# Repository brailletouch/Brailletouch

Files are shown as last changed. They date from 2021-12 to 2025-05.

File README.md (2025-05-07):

# BrailleTouch
Dispositivo Braille Digital Asequible y Open Source para Personas con Discapacidad Visual y Sordocieguera / Affordable and Open Source Digital Braille Device for Visually Impaired and Deafblind People

**¡Bienvenidos al repositorio del Proyecto BrailleTouch! / Welcome to the BrailleTouch Project repository!**

Este es un proyecto en **desarrollo activo**. La información, componentes y ejemplos mostrados reflejan el estado actual o intentos iniciales. Estamos explorando y desarrollando continuamente nuevas y más eficientes soluciones que se actualizarán aquí una vez validadas. ¡Tu participación es bienvenida en cada etapa!

This is a project in **active development**. The information, components, and examples shown reflect the current state or initial attempts. We are continuously exploring and developing new and more efficient solutions, which will be updated here once validated. Your participation is welcome at every stage!

Este proyecto es una iniciativa social de código abierto (Open Source) dedicada a democratizar el acceso a la tecnología Braille digital. Nuestro objetivo es reducir significativamente el alto costo de los dispositivos Braille actuales y proporcionar una herramienta innovadora, portátil y asequible que empodere a personas ciegas y sordociegas, mejorando su alfabetización, independencia, comunicación y participación plena en la sociedad.

This project is an open-source social initiative dedicated to democratizing access to digital Braille technology. Our goal is to significantly reduce the high cost of current Braille devices and provide an innovative, portable, and affordable tool that empowers blind and deafblind individuals, improving their literacy, independence, communication, and full participation in society.

---

## El Problema: Acceso Limitado a Tecnología Braille Digital Esencial / The Problem: Limited Access to Essential Digital Braille Technology

La tecnología Braille digital, como las pantallas Braille actualizables, es fundamental para la alfabetización, educación, empleo y acceso a la información en el mundo digital para personas con discapacidad visual. Sin embargo, su costo es prohibitivo. Dispositivos comerciales básicos cuestan más de $1,200 USD, y los de buena calidad oscilan entre $3,000 y $6,000 USD o incluso más.

Esta barrera económica es especialmente crítica para la comunidad sordociega. Para muchas personas que no pueden depender de la vista ni el oído, el Braille es la única vía autónoma para acceder al lenguaje escrito y al mundo digital. La inaccesibilidad de la tecnología Braille debido a su precio exacerba el riesgo de aislamiento y limita drásticamente sus oportunidades.

The high cost of current digital Braille technology, such as refreshable Braille displays, is a major barrier. Basic commercial devices cost over $1,200 USD, and good quality ones range from $3,000 to $6,000 USD or even more.

This economic barrier is particularly critical for the deafblind community. For many who cannot rely on sight or hearing, Braille is the only autonomous path to access written language and the digital world. The inaccessibility of Braille technology due to its price exacerbates the risk of isolation and drastically limits their opportunities.

---

## Nuestra Solución: BrailleTouch - Un Enfoque Innovador y Asequible / Our Solution: BrailleTouch - An Innovative and Affordable Approach

El Proyecto BrailleTouch aborda este problema desarrollando un dispositivo Braille electrónico de código abierto, diseñado para ser significativamente más asequible que las alternativas comerciales. Esto no es aún un producto terminado, sino un proyecto en desarrollo. Nuestra innovación clave para reducir costos y complejidad es radicalmente diferente:

The BrailleTouch Project addresses this problem by developing an open-source electronic Braille device, designed to be significantly more affordable than commercial alternatives. This is not a finished product yet, but a project under development. Our key innovation to reduce cost and complexity is radically different:

En lugar de utilizar múltiples celdas Braille físicas y costosas (cada celda individual puede costar $100-$150+ USD), BrailleTouch combina:

Instead of using multiple expensive physical Braille cells (each individual cell can cost $100-$150+ USD), BrailleTouch combines:

1.  Una **única celda Braille física** de alta calidad y rápida respuesta.
2.  Una **matriz de sensores táctiles** de bajo costo, que funciona como "celdas virtuales" que representan una línea de texto digital.

1.  A **single physical Braille cell** with high quality and fast response.
2.  A low-cost **tactile sensor matrix** that acts as "virtual cells" representing a line of digital text.

El usuario interactúa tocando la matriz táctil para "navegar" por la línea de texto digital. Al tocar una posición virtual, la única celda física, bajo otro dedo, se actualiza instantáneamente para mostrar el carácter que corresponde a esa posición. Esto simula la experiencia de leer una línea completa, carácter por carácter, permitiendo al usuario percibir la estructura del texto con mucho menos hardware.

The user interacts by touching the tactile matrix to "navigate" through the digital text line. By touching a virtual position, the single physical cell, under another finger, instantly updates to show the character corresponding to that position. This simulates the experience of reading a full line, character by character, allowing the user to perceive the text structure with much less hardware.

Estimamos que este enfoque puede reducir el costo del subsistema Braille en al menos un 95%, y el costo total del dispositivo en más de un 90% en comparación con las pantallas Braille actuales.

We estimate this approach can reduce the cost of the Braille subsystem by at least 95%, and the total device cost by over 90% compared to current Braille displays.

---

## Funcionalidades Clave y Potencial / Key Functionalities and Potential

BrailleTouch está diseñado para ofrecer una solución versátil:

BrailleTouch is designed to offer a versatile solution:

*   **Lectura de Texto:** Actúa como una pantalla Braille portátil y asequible para leer libros, documentos, correos electrónicos y navegar en la web. La matriz táctil ayuda a la orientación espacial en textos estructurados.
*   **Comunicación en Tiempo Real ("Oído Táctil"):** Crucial para personas sordociegas. Usando solo la celda física, permite recibir información hablada (vía transcripción automática con IA) de forma continua y fluida, como un "oído táctil". Su rapidez supera a las pantallas multicelda para este uso, esencial para seguir conversaciones, clases o eventos en vivo.
*   **Escritura Braille:** Incluirá un teclado Braille táctil integrado para entrada de texto bidireccional.
*   **Potencial con IA:** Se planea integrar IA para funciones avanzadas como reconocimiento de voz ambiental (con identificación de hablantes), resumen adaptativo, traducción multi-idioma y reconocimiento de imagen, abriendo un mundo de independencia sin precedentes.
*   **Alfabetización Temprana Autónoma:** Permite a niños sordociegos aprender Braille y lenguaje recibiendo información del entorno de forma continua, incluso sin padres/maestros que sepan Braille.

*   **Text Reading:** Acts as a portable and affordable Braille display for reading books, documents, emails, and browsing the web. The tactile matrix aids spatial orientation in structured texts.
*   **Real-Time Communication ("Tactile Ear"):** Crucial for deafblind individuals. Using only the physical cell, it enables receiving spoken information (via automatic AI transcription) continuously and fluently, like a "tactile ear". Its speed surpasses multi-cell displays for this use, essential for following live conversations, classes, or events.
*   **Braille Writing:** Will include an integrated tactile Braille keyboard for bidirectional text input.
*   **AI Potential:** AI integration is planned for advanced features like ambient voice recognition (with speaker identification), adaptive summarization, multi-language translation, and image recognition, opening up a world of unprecedented independence.
*   **Autonomous Early Literacy:** Enables deafblind children to learn Braille and language by receiving environmental information continuously, even without parents/teachers who know Braille.

---

## Estructura del Proyecto / Project Structure

El proyecto consta principalmente de 3 partes interconectadas:

The project consists mainly of 3 interconnected parts:

1.  **Diseño Físico del Dispositivo:** Creación de un diseño eficiente, ergonómico y de bajo costo para la celda Braille, la matriz táctil, los botones y la carcasa (explorando impresión 3D).
2.  **Diseño de la Electrónica y Firmware:** Desarrollo del hardware (ej. ESP32, controladores PWM, multiplexores) y el software interno que controla el dispositivo y la comunicación.
3.  **Diseño del Software/Interfaz:** Creación/adaptación de software para la traducción de texto a Braille, gestión de entrada, y compatibilidad con lectores de pantalla de código libre (NVDA, BrailleBack, BRLTTY) y futuras integraciones (apps móviles, IA).

1.  **Physical Device Design:** Creation of an efficient, ergonomic, and low-cost design for the Braille cell, tactile matrix, buttons, and case (exploring 3D printing).
2.  **Electronics and Firmware Design:** Development of the hardware (e.g., ESP32, PWM controllers, multiplexers) and the internal software that controls the device and communication.
3.  **Software/Interface Design:** Creation/adaptation of software for text-to-Braille translation, input management, and compatibility with open-source screen readers (NVDA, BrailleBack, BRLTTY) and future integrations (mobile apps, AI).

---

## Componentes Explorados en Intentos Iniciales / Components Explored in Initial Attempts

**Importante:** Esta sección detalla los componentes **utilizados o explorados en intentos iniciales**. El proyecto está en **desarrollo activo** y se están buscando soluciones **más eficientes y optimizadas** para el diseño final. Los componentes listados aquí sirvieron para dar ideas generales de formas sencillas de realizar un dispositivo, pero **no representan el conjunto final funcional**.

**Important:** This section details the components **used or explored in initial attempts**. The project is in **active development** and **more efficient and optimized** solutions are being sought for the final design. The components listed here served to give general ideas of simple ways to create a device, but **do not represent the final functional set**.

*   1 ESP32.
*   4 Servo motores / Servo motors. (Nota: Estos se usaron en intentos iniciales para mover pines junto con un sensor de ubicación. Se identificó que **no son lo suficientemente rápidos, son ruidosos y pueden desgastarse con el uso**. Aunque fueron útiles para empezar, la estrategia actual busca **actuadores más rápidos y fiables**. ¡Estamos trabajando en mejoras increíbles que se documentarán aquí una vez validadas!)
*   4 PCF8574 Multiplexor/Demultiplexor 8 Canales / PCF8574 Multiplexer/Demultiplexer 8 Channels
*   1 Celda braille (se exploraron mecanismos de actuador de celda con 4 servo motores para mover 8 pines; se busca compatibilidad con distintas tecnologías de actuador más eficientes como piezoeléctrica o de solenoide; la clave es usar SOLO una celda física ya que los movimientos en la línea completa se simulan en la interfaz táctil virtual) / 1 Braille cell (cell actuator mechanisms were explored with 4 servo motors to move 8 pins; compatibility with different, more efficient actuator technologies like piezoelectric or solenoid is sought; the key is to use ONLY one physical cell as full-line movements are simulated on the virtual tactile interface).
*   1 Caja para su ensamblaje (explorando impresión 3D) / 1 Box for assembly (exploring 3D printing).
*   1 Controlador PWM para mover todos los pines de manera simultánea y obtener lecturas más rápidas (aplicado a intentos con servos) / 1 PWM controller to move all pins simultaneously and get faster readings (applied to attempts with servos).
*   Botones del teclado táctil integrado y cable para conexiones / Integrated tactile keyboard buttons and connection cables.
*   Matriz de sensores táctiles (PCB, aún en desarrollo; intentos buscan controlar ~200 posiciones con pines táctiles del ESP32) / Tactile sensor matrix (PCB, still under development; attempts aim to control ~200 positions with ESP32 touch pins).
*   Opcional (para desarrollo o funcionalidades avanzadas): / Optional (for development or advanced functionalities):
    *   Una pantalla para monitorear el texto / A screen if you want to monitor the text.
    *   Un conector PS/2 si se quiere usar un teclado externo para escribir (alternativa a teclado USB/Bluetooth) / A PS/2 connector if you want to use an external keyboard for writing (alternative to USB/Bluetooth keyboard).
    *   Componentes para integración IA (hardware potente si es necesario) / Components for AI integration (powerful hardware if needed).
    *   Módulo de micrófono y circuitos de audio (para transcripción de voz) / Microphone module and audio circuits (for voice transcription).

---

## Imágenes de Referencia (Intentos Iniciales/Conceptos) / Reference Images (Initial Attempts/Concepts)

Las imágenes a continuación muestran **prototipos o intentos iniciales** para ilustrar el concepto y la estructura general del proyecto utilizando los componentes explorados. **NO representan el diseño final o un dispositivo completamente funcional.** El proyecto está en **desarrollo activo** y se están buscando soluciones **más eficientes y optimizadas**. Estas imágenes se mantienen aquí como **referencia histórica de los intentos iniciales**. Actualizaremos estas imágenes a medida que el desarrollo avance y se validen nuevas soluciones en este repositorio (`brailletouch/Brailletouch`).

The images below show **early prototypes or initial attempts** to illustrate the project's concept and general structure using the components explored. **They DO NOT represent the final design or a fully functional device.** The project is in **active development**, and **more efficient and optimized** solutions are being sought. These images are kept here as **historical reference of initial attempts**. We will update these images as development progresses and new solutions are validated in this repository (`brailletouch/Brailletouch`).

*   **Nota:** Los siguientes enlaces de imágenes apuntan a su ubicación original en otro repositorio o fuente externa (`discapacidad5` o `user-images`). Para que se muestren correctamente, deben estar accesibles en esas ubicaciones originales o ser subidas a este repositorio y actualizar los enlaces.
*   **Note:** The following image links point to their original location in another repository or external source (`discapacidad5` or `user-images`). For them to display correctly, they must remain accessible at those original locations or be uploaded to this repository and have the links updated.





reference [http://www.esp32learning.com/code/esp32-and-a-pcf8574-expander-example.php](http://www.esp32learning.com/code/esp32-and-a-pcf8574-expander-example.php)
PCF8574 library [https://www.arduino.cc/reference/en/libraries/pcf8574-library/](https://www.arduino.cc/reference/en/libraries/pcf8574-library/)








---

## Licencia / License

Este proyecto está bajo la **Licencia Abierta y Comunitaria Braille Touch (BTAC) v1.2**. Esta licencia garantiza que todo el código, hardware, conceptos, metodologías, mecanismos, innovaciones tecnológicas, invenciones y cualquier otra creación o desarrollo relacionado con el proyecto Braille Touch permanezcan abiertos y accesibles, y no puedan ser privatizados.

This project is licensed under the **Braille Touch Open and Community License (BTAC) v1.2**. This license ensures that all code, hardware, concepts, methodologies, mechanisms, technological innovations, inventions, and any other creations or developments related to the Braille Touch project remain open and accessible and cannot be privatized.

### Permisos / Permissions
- Puedes usar, copiar, modificar, distribuir y comercializar el código, hardware, conceptos, innovaciones y derivados del proyecto bajo las condiciones de esta licencia. / You may use, copy, modify, distribute, and commercialize the code, hardware, concepts, innovations, and derivatives of the project under the conditions of this license.

### Registro de Modificaciones / Modification Record
- Las modificaciones y mejoras deben incluir un registro detallado de todas las personas y entidades involucradas, con una descripción clara y enlaces al repositorio original. / Modifications and improvements must include a detailed record of all individuals and entities involved, with a clear description and links to the original repository.

### No Privatización / No Privatization
- El código y las innovaciones no pueden ser privatizados. Todo trabajo derivado debe permanecer bajo esta misma licencia. / The code and innovations cannot be privatized. All derivative work must remain under this same license.

### Compatibilidad y Comercialización / Compatibility and Commercialization
- Cualquier trabajo derivado debe ser distribuido bajo la misma licencia. La comercialización está permitida siempre que se respeten las condiciones de la licencia. / Any derivative work must be distributed under the same license. Commercialization is allowed as long as the license conditions are respected.

Para más detalles sobre la licencia, por favor revisa el archivo [LICENCIA](https://github.com/brailletouch/Brailletouch/blob/main/LICENCIA.md) en el repositorio. / For more details about the license, please review the [LICENSE](https://github.com/brailletouch/Brailletouch/blob/main/LICENSE.md) file in the repository.

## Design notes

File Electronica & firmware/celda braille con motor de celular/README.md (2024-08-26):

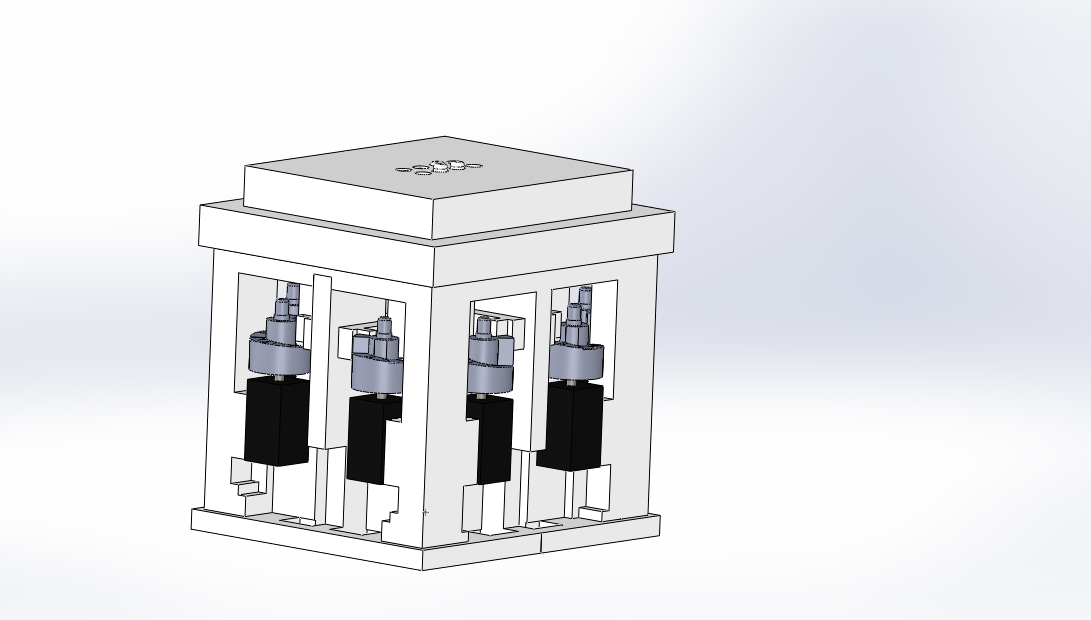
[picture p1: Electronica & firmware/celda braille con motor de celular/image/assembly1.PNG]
Celda Braille 3D
.

### **3D-Printed Braille Cell**

#### **Description**

This project details the construction of a Braille cell using cellphone vibrating motors. The cell is designed to be 3D printed and offers 
an accessible and customizable solution for visually impaired individuals.

#### **Key Components**

* **Vibrating Motors:** 8 individual vibrating motors, each responsible for raising one Braille dot.
* **L9110 Motor Drivers:** Used to control the direction of the vibrating motors.
* **74LS04 Logic Inverter:** Inverts the logic signal to control the motor direction with a single ESP32 pin.
* **ESP32:** Main microcontroller that generates the control signals for the motors.
* **Limit Switches (transistors):** Detect when the motors reach their limits and cut power to prevent damage.
* **3D Design:** The 3D files for the Braille cell are available in this repository for download and printing.

#### **Operation**

1. **Direction Control:**
   * A single pin of the ESP32 controls both directions of a motor.
   * When the pin is high, the motor rotates in one direction.
   * The 74LS04 inverts the signal when the pin is low, causing the motor to rotate in the opposite direction.

2. **Motor Stopping:**
   * The limit switches (transistors) detect when the motors reach the physical limits.
   * Upon detection, the switch cuts power to the corresponding motor, preventing it from continuing to rotate.

#### **Assembly Instructions**

1. **3D Printing:** Print all the parts using a compatible 3D printer.
2. **Assembly:** An assembled 3D file is provided as a reference in "assembly.STEP".
3. **Electrical Connection:** Connect the electronic components according to the schematic diagram provided in "schematic.png".
4. **Software Setup:** Upload the ESP32 firmware to the device. Replace the `Braille_disp(dato)` function with a custom function that
5. provides detailed control of each motor.

#### **Files**

* **3D Files:** Contain the 3D models of all Braille cell parts.
* **Schematic Diagram:** Shows the connection of all electronic components.
* **Firmware:** Source code for the ESP32.
* **Documentation:** Additional documentation about the project.

#### **Contributions**

Contributions are welcome. If you find any errors or want to improve this project, feel free to open an issue or submit a pull request.

___________________________________________________________________________________________________________________________________________________________________________________
### **Celda Braille Impresa en 3D**

#### **Descripción**

Este proyecto detalla la construcción de una celda Braille utilizando motores vibratorios de teléfonos móviles. 
La celda está diseñada para ser impresa en 3D y ofrece una solución accesible y personalizable para personas con discapacidad visual.

#### **Componentes Clave**

* **Motores vibratorios:** 8 motores vibratorios individuales, cada uno responsable de levantar un punto Braille.
* **Controladores de motor L9110:** Utilizados para controlar la dirección de los motores vibratorios.
* **Inversor lógico 74LS04:** Invierte la señal lógica para controlar la dirección de los motores con un solo pin del ESP32.
* **ESP32:** Microcontrolador principal que genera las señales de control para los motores.
* **Interruptores (transistores):** Detectan cuando los motores alcanzan los topes y cortan la alimentación para evitar daños.
* **Diseño 3D:** Los archivos 3D de la celda Braille están disponibles en este repositorio para su descarga e impresión.

#### **Funcionamiento**

1. **Control de dirección:**
   * Un solo pin del ESP32 controla ambas direcciones de un motor.
   * Cuando el pin está en alto, el motor gira en una dirección.
   * El 74LS04 invierte la señal cuando el pin está en bajo, haciendo que el motor gire en la dirección opuesta.

2. **Detención de motores:**
   * Los interruptores (transistores) detectan cuando los motores alcanzan los topes físicos.
   * Al detectar un tope, el interruptor corta la alimentación al motor correspondiente, evitando que continúe girando.

#### **Instrucciones de montaje**

1. **Impresión 3D:** Imprime todas las piezas utilizando una impresora 3D compatible.
2. **Ensamblaje:** Un archivo 3D ensamblado se proporciona como referencia en "assembly.STEP".
3. **Conexión eléctrica:** Conecta los componentes electrónicos según el diagrama esquemático proporcionado en "schematic.png".
4. **Configuración del software:** Carga el firmware del ESP32 en el dispositivo. Reemplaza la función `Braille_disp(dato)` con la función
5. personalizada que proporciona el control detallado de cada motor.

#### **Archivos**

* **Archivos 3D:** Contienen los modelos 3D de todas las piezas de la celda Braille.
* **Diagrama esquemático:** Muestra la conexión de todos los componentes electrónicos.
* **Firmware:** Código fuente para el ESP32.
* **Documentación:** Documentación adicional sobre el proyecto.

#### **Contribuciones**

Las contribuciones son bienvenidas. Si encuentras algún error o deseas mejorar este proyecto, no dudes en abrir un issue o enviar una pull request.

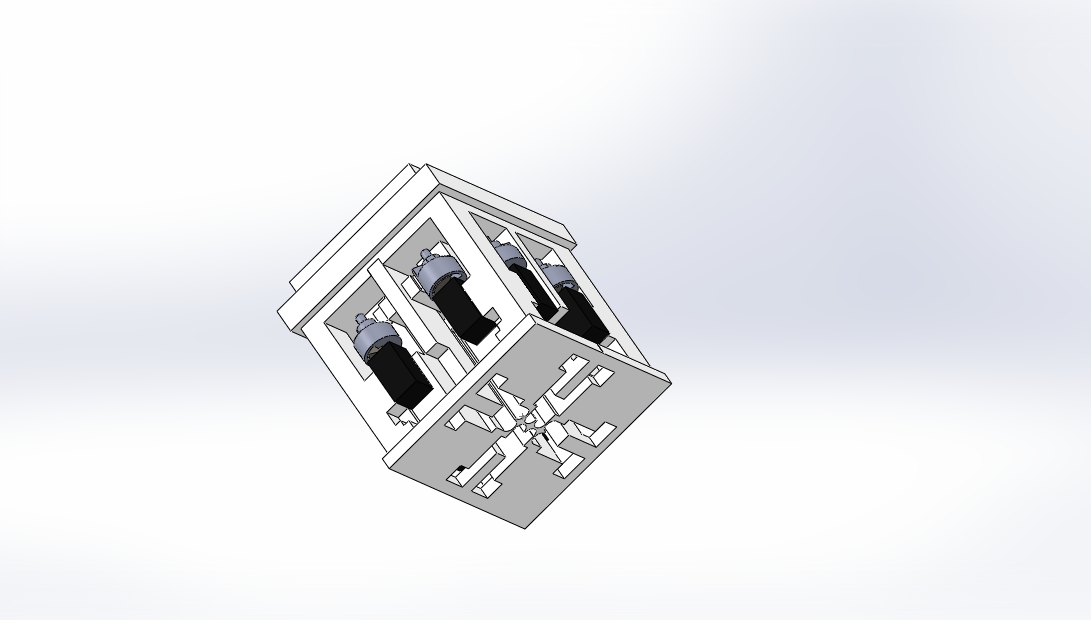
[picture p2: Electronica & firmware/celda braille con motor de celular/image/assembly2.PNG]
Celda Braille 3D
.

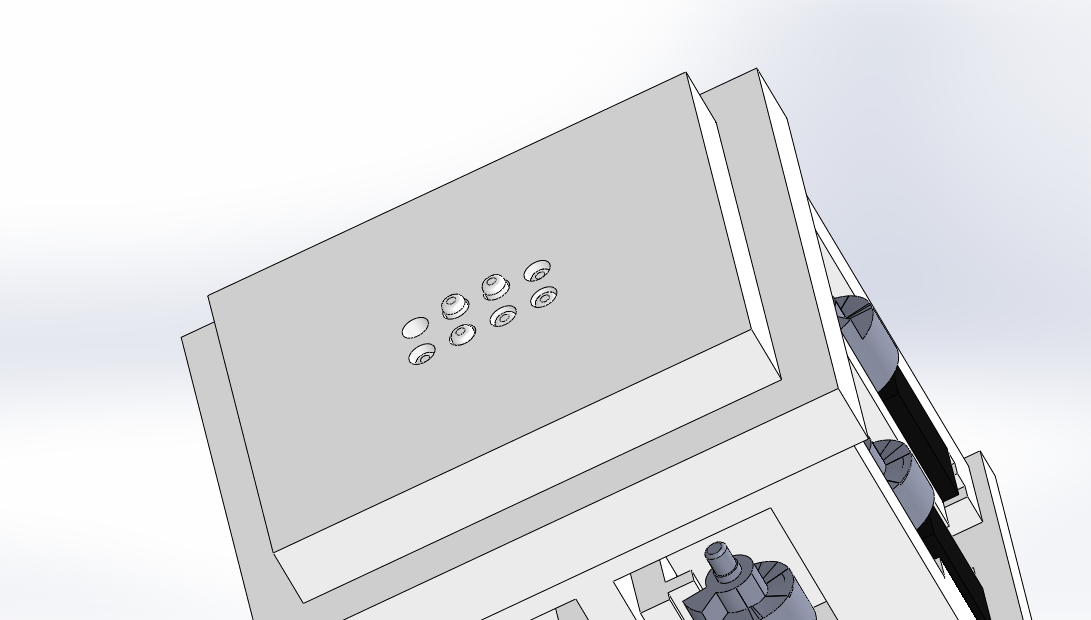
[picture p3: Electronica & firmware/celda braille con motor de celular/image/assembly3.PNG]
Celda Braille 3D
.

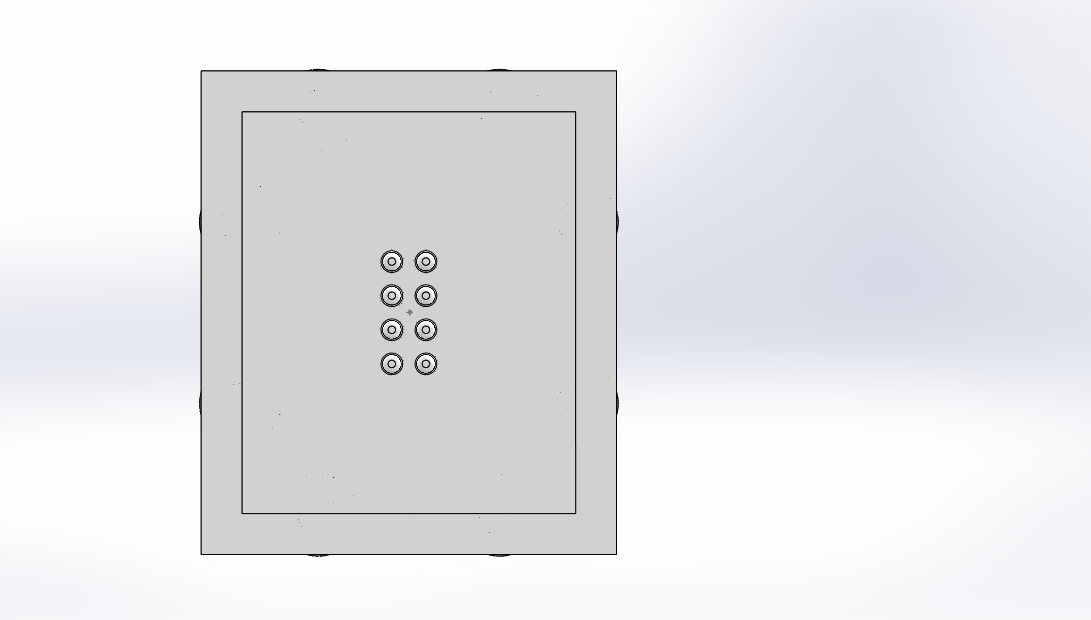
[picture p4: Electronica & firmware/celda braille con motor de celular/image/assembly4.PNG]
Celda Braille 3D
.

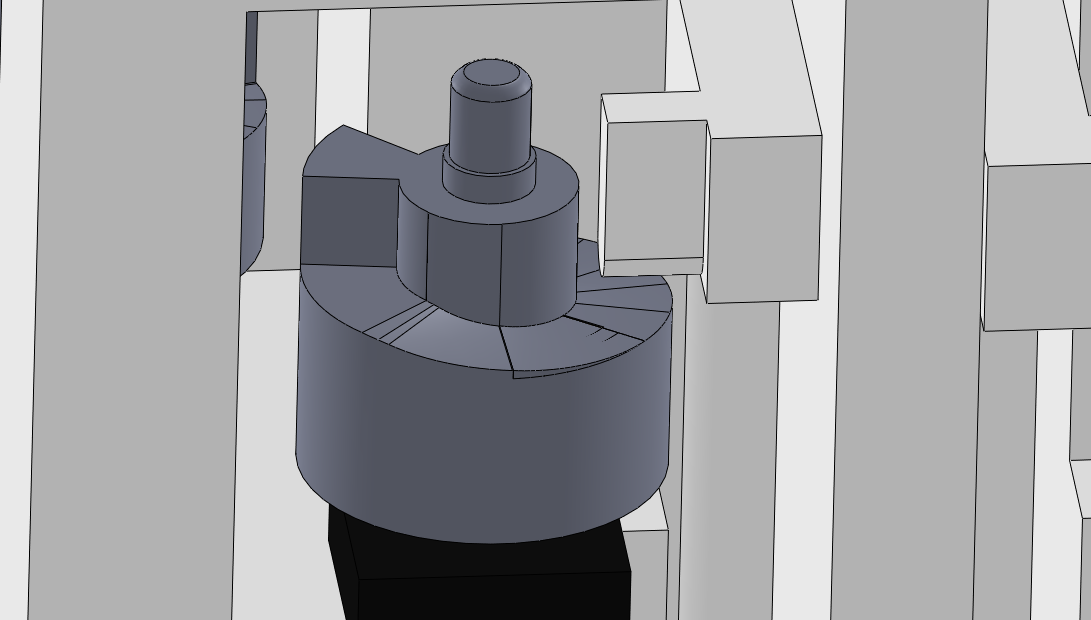
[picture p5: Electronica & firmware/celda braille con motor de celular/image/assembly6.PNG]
Celda Braille 3D
.

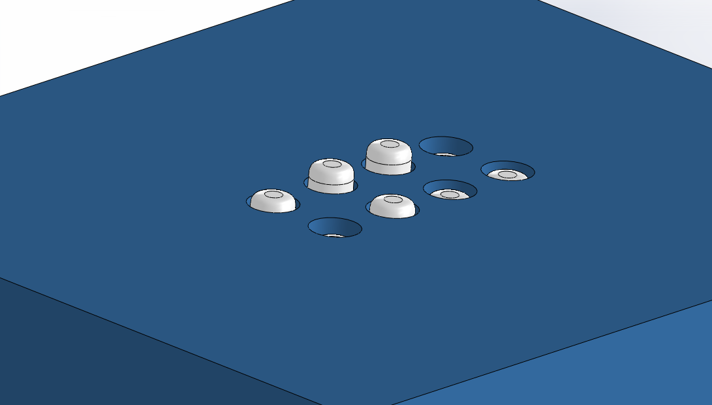
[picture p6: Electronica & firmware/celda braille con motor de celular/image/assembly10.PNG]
Celda Braille 3D
.

## Licencia / License

Este proyecto está bajo la **Licencia Abierta y Comunitaria Braille Touch (BTAC) v1.2**. Esta licencia garantiza que todo el código, hardware, conceptos, metodologías, mecanismos, innovaciones tecnológicas, invenciones y cualquier otra creación o desarrollo relacionado con el proyecto Braille Touch permanezcan abiertos y accesibles, y no puedan ser privatizados.

This project is licensed under the **Braille Touch Open and Community License (BTAC) v1.2**. This license ensures that all code, hardware, concepts, methodologies, mechanisms, technological innovations, inventions, and any other creations or developments related to the Braille Touch project remain open and accessible and cannot be privatized.

### Permisos / Permissions
- Puedes usar, copiar, modificar, distribuir y comercializar el código, hardware, conceptos, innovaciones y derivados del proyecto bajo las condiciones de esta licencia. / You may use, copy, modify, distribute, and commercialize the code, hardware, concepts, innovations, and derivatives of the project under the conditions of this license.

### Registro de Modificaciones / Modification Record
- Las modificaciones y mejoras deben incluir un registro detallado de todas las personas y entidades involucradas, con una descripción clara y enlaces al repositorio original. / Modifications and improvements must include a detailed record of all individuals and entities involved, with a clear description and links to the original repository.

### No Privatización / No Privatization
- El código y las innovaciones no pueden ser privatizados. Todo trabajo derivado debe permanecer bajo esta misma licencia. / The code and innovations cannot be privatized. All derivative work must remain under this same license.

### Compatibilidad y Comercialización / Compatibility and Commercialization
- Cualquier trabajo derivado debe ser distribuido bajo la misma licencia. La comercialización está permitida siempre que se respeten las condiciones de la licencia. / Any derivative work must be distributed under the same license. Commercialization is allowed as long as the license conditions are respected.

Para más detalles sobre la licencia, por favor revisa el archivo [LICENCIA](https://github.com/brailletouch/Brailletouch/blob/main/LICENCIA.md)  en el repositorio. / For more details about the license, please review the [LICENSE](https://github.com/brailletouch/Brailletouch/blob/main/LICENSE.md) file in the repository.

---

Para más información, visita nuestro repositorio en [GitHub](https://github.com/brailletouch/Brailletouch). / For more information, visit our repository on [GitHub](https://github.com/brailletouch/Brailletouch).

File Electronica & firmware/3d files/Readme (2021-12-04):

Esta carpeta contiene los modelos de piezas en 3D para editar e imprimir

This folder contains the 3D part models for editing and printing

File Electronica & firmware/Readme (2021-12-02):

# Esta carpeta contiene esquematicos de la electronica y codigos .ino

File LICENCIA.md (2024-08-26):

# Licencia Abierta y Comunitaria Braille Touch (BTAC) v1.2
##  **Version 1.2, Agosto 26, 2024**

### 1. Definición y Alcance de la Licencia
La **Licencia Abierta y Comunitaria Braille Touch (BTAC)** es una licencia de copyleft fuerte que garantiza que todo el código, hardware, conceptos, metodologías, mecanismos, innovaciones tecnológicas, invenciones y cualquier otra creación o desarrollo relacionado con el proyecto Braille Touch permanezcan abiertos, accesibles y no puedan ser privatizados en ninguna circunstancia.

Esta licencia cubre, pero no se limita a:
- Código fuente y software.
- Hardware y componentes físicos.
- Diseños de dispositivos.
- Conceptos y metodologías innovadores.
- Mecanismos y procesos desarrollados dentro del marco del proyecto.
- Cualquier invención o creación derivada, ya sea técnica, tecnológica o conceptual.

### 2. Permisos Otorgados por la Licencia
Cualquier persona o entidad tiene el derecho de:
- Usar, copiar, modificar, distribuir y comercializar el código, hardware, conceptos, innovaciones y derivados del proyecto, siempre que se respeten las condiciones descritas en esta licencia.

Las modificaciones, mejoras o innovaciones deben permanecer disponibles para la comunidad bajo esta misma licencia.

### 3. Registro de Modificaciones y Contribuciones
Cada vez que se realice una modificación, mejora o nueva innovación, se debe incluir un registro detallado de todas las personas y entidades involucradas. Este registro debe incluir:
- Nombre del contribuyente o entidad.
- Enlace a su repositorio, sitio web o lugar donde se publique su trabajo (si aplica).
- Descripción clara y detallada de la contribución (código, hardware, concepto, metodología, etc.).

Este registro debe hacer referencia siempre al proyecto Braille Touch original y al diseño, así como a todas las contribuciones anteriores que se hayan integrado en la versión que se está utilizando.

El registro debe estar presente y visible en:
- Documentación del proyecto.
- Código fuente.
- Esquemas de diseño o archivos de hardware.
- Cualquier documento o presentación de conceptos o metodologías innovadoras.

### 4. Referencias y Menciones
Todo trabajo derivado debe incluir:
- Una referencia clara y visible al proyecto **Braille Touch** original.
- Enlaces al sitio web oficial y al repositorio del proyecto original.
- Menciones detalladas de todas las contribuciones y modificaciones anteriores que se hayan incorporado al trabajo derivado, manteniendo una cadena de atribuciones que refleje la evolución del proyecto desde su inicio.

### 5. No Privatización
El código, hardware, metodologías, conceptos y cualquier otro aspecto cubierto por esta licencia no pueden ser privatizados ni utilizados en proyectos cerrados. Todo trabajo derivado debe permanecer abierto bajo esta misma licencia, asegurando que cualquier innovación relacionada con el proyecto Braille Touch sea accesible para todos y continúe siendo de código abierto y de tecnología abierta.

Este principio se extiende a:
- Software y código fuente.
- Hardware y dispositivos físicos.
- Diseños e invenciones.
- Conceptos y metodologías.
- Mecanismos y procesos.

### 6. Compatibilidad de la Licencia
Cualquier trabajo derivado, ya sea que utilice parte o la totalidad del código, hardware, metodologías o innovaciones cubiertas por esta licencia, debe ser distribuido bajo la **Licencia BTAC** sin excepción. Esto asegura que todo el trabajo relacionado permanezca accesible, abierto y no pueda ser apropiado para proyectos privados o cerrados.

Esta licencia también garantiza que cualquier innovación conceptual o tecnológica basada en el proyecto original debe permanecer bajo esta licencia, protegiendo todas las contribuciones futuras.

### 7. Comercialización
El código, hardware, conceptos, metodologías y productos derivados pueden ser comercializados por cualquier persona o entidad, siempre que:
- El código y las innovaciones permanezcan abiertos y disponibles públicamente bajo esta licencia.
- Se respeten las condiciones de registro, mención de contribuyentes y atribución al proyecto original.

No hay restricciones en la comercialización siempre que el acceso al conocimiento y las innovaciones derivadas permanezcan libres y orientados a la comunidad.

### 8. Publicación de Modificaciones e Innovaciones
Todas las modificaciones, mejoras o innovaciones tecnológicas o conceptuales deben:
- Publicarse en un repositorio accesible públicamente, preferiblemente asociado con el proyecto original.
- Notificarse al proyecto original, proporcionando detalles sobre la naturaleza de la modificación o innovación.

Este requisito asegura transparencia en el desarrollo del proyecto y garantiza que la comunidad pueda beneficiarse de todas las mejoras realizadas.

### 9. Inclusión de Innovaciones y Nuevas Metodologías
Cualquier innovación, ya sea en software, hardware, conceptos, procesos o mecanismos, debe ser documentada y añadida a una lista de mejoras que forman parte del proyecto original. Esto incluye, pero no se limita a:
- Innovaciones en software y código fuente.
- Nuevas metodologías o conceptos aplicados al proyecto.
- Mecanismos o procesos físicos que mejoran el diseño o funcionamiento del hardware.
- Cualquier invención o tecnología derivada del proyecto.

### 10. Preservación de la Licencia
Esta licencia no puede ser modificada o reemplazada por una licencia más restrictiva o que permita la privatización. Cualquier trabajo derivado debe continuar bajo la **Licencia BTAC**, preservando el acceso abierto, la colaboración y el espíritu comunitario del proyecto.

Esta protección cubre todo código, hardware, conceptos, metodologías, invenciones, innovaciones, mecanismos o procesos desarrollados como parte del proyecto.

### 11. Atribución al Proyecto Original
Todo trabajo derivado o modificado debe incluir una clara atribución al proyecto **Braille Touch** original y un enlace al sitio web oficial o al repositorio original. Esto debe estar presente en:
- Documentación del proyecto.
- Código fuente.
- Hardware y dispositivos físicos.
- Cualquier innovación conceptual o metodológica derivada del proyecto.

### 12. Protección de Patentes
Al aceptar esta licencia, cualquier persona o entidad acuerda no reclamar ni hacer cumplir patentes sobre ningún aspecto del código, hardware, concepto, metodología, mecanismo o innovación derivada del proyecto Braille Touch. Esto asegura que todas las innovaciones bajo esta licencia permanezcan abiertas y no sujetas a restricciones legales.

### 13. Inclusión de Conceptos y Metodologías Innovadoras
Esta licencia cubre no solo el código y el hardware, sino también conceptos innovadores, metodologías y cualquier invención asociada con el proyecto. Cualquiera que contribuya con una nueva metodología, mecanismo o concepto al proyecto debe asegurarse de que esté documentado y disponible públicamente para su uso y mejora bajo esta misma licencia.

### 14. Continuidad de la Comunidad
El propósito de esta licencia es fomentar una comunidad colaborativa donde todas las contribuciones, ya sean técnicas, conceptuales o metodológicas, sean reconocidas y permanezcan abiertas para su uso, mejora y distribución. Al participar en este proyecto, cada contribuyente acepta seguir estos principios y ayudar a preservar el acceso abierto al conocimiento.

### 15. Ley y Jurisdicción Aplicables
15.1 Jurisdicción: Esta licencia se rige por las leyes del país donde se encuentra el proyecto original.

15.2 Resolución de Disputas: Cualquier disputa o controversia relacionada con esta licencia se resolverá mediante arbitraje en el país donde se encuentra el proyecto original.

### 16. Aceptación
16.1 Aceptación de Términos: Al usar, distribuir, modificar o mejorar el Código Original, el Diseño Original, el Código Modificado o el Diseño Modificado, el licenciatario acepta los términos y condiciones de esta licencia.

### 17. Autorización
17.1 Uso de la Licencia: Cualquier persona o entidad está autorizada a usar esta licencia y a proporcionar una copia de la misma.

### 18. Versiones de la Licencia
18.1 Modificaciones: Esta licencia puede ser modificada o actualizada en cualquier momento.

18.2 Nueva Versión: Cualquier versión modificada o actualizada de la licencia será considerada una nueva versión de la misma.

### 19. Disposiciones Generales
19.1 Acuerdo Completo: Esta licencia constituye el acuerdo completo y final entre las partes.

19.2 Divisibilidad: Si alguna disposición de esta licencia se considera inválida o inaplicable, las disposiciones restantes seguirán en vigor.

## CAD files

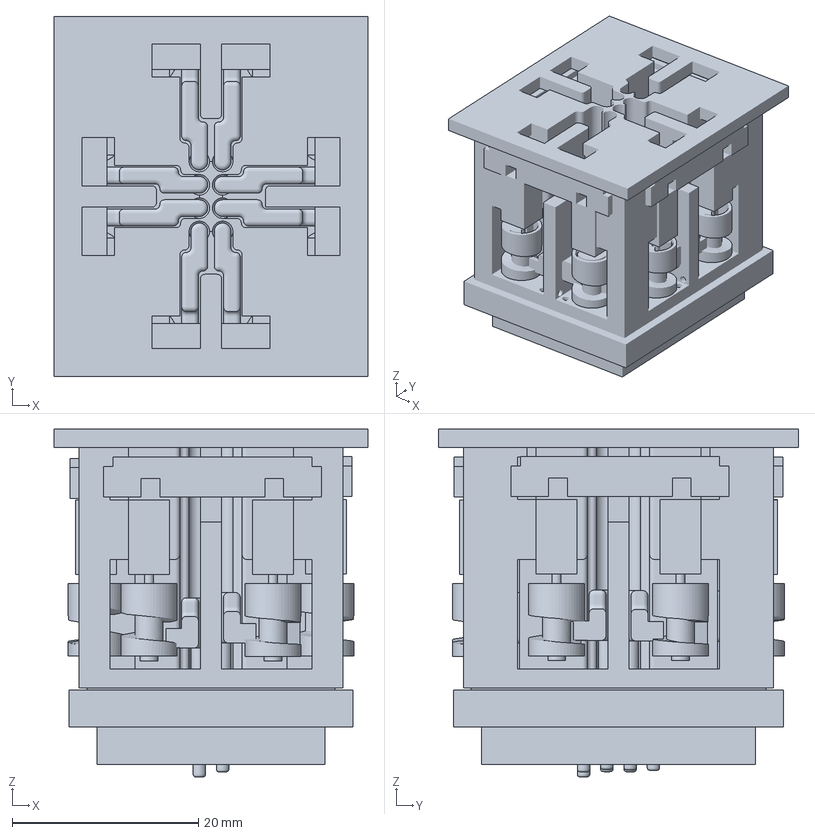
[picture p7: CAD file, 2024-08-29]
Electronica & firmware/celda braille con motor de celular/3D Manufacture Format/assembly3.3MF
33.7 x 38.7 x 37.4 mm

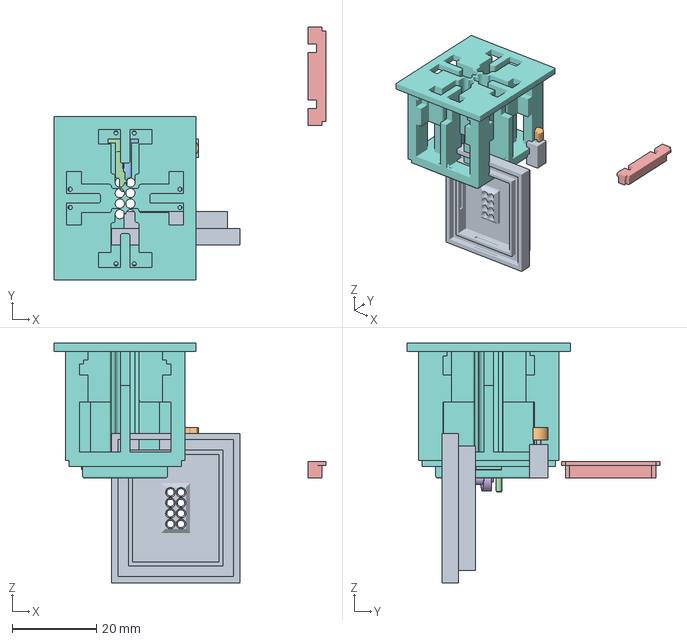
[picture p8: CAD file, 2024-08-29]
Electronica & firmware/celda braille con motor de celular/Additive Manufacturing File/assembly3.AMF
64.5 x 60.0 x 56.8 mm

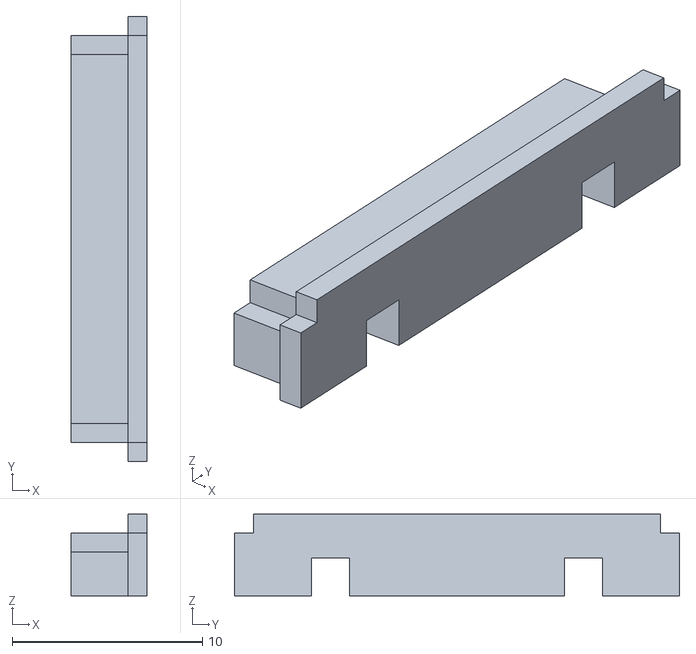
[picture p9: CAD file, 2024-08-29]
Electronica & firmware/celda braille con motor de celular/STL/assembly3 - soporte17-12.STL
4.00 x 23.4 x 4.30

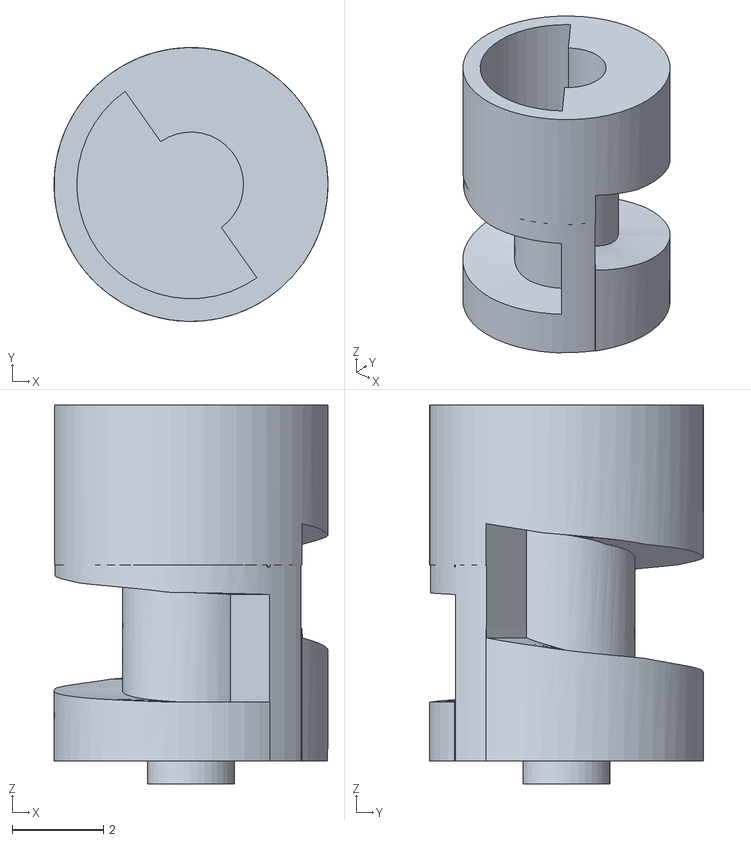
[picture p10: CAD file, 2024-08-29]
Electronica & firmware/celda braille con motor de celular/STL/assembly3 - CAPUCHAMOTOR17-30.STL
6.00 x 6.00 x 8.30

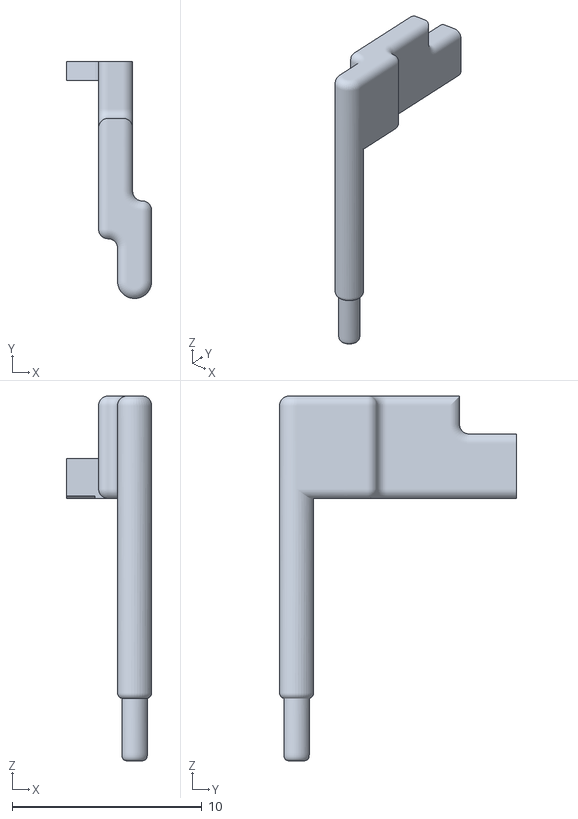
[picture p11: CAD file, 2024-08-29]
Electronica & firmware/celda braille con motor de celular/STL/assembly3 - Pinizquierdo17-14.STL
4.50 x 12.5 x 19.3

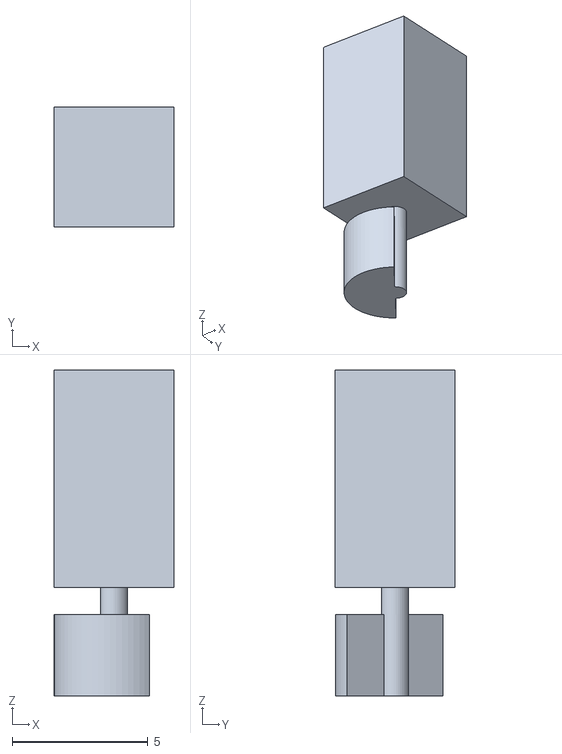
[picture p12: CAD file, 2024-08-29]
Electronica & firmware/celda braille con motor de celular/STL/assembly3 - motor-11.STL
4.40 x 4.40 x 12.0

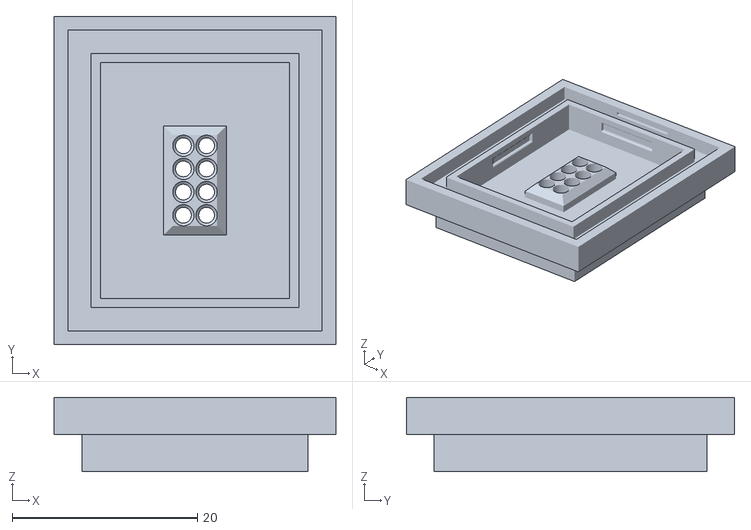
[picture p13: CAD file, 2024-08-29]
Electronica & firmware/celda braille con motor de celular/STL/assembly3 - TAPA_17-1.STL
30.4 x 35.5 x 8.00

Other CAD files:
Electronica & firmware/celda braille con motor de celular/STEP/assembly3.STEP
Electronica & firmware/celda braille con motor de celular/STL/assembly3 - soporte17-13.STL
Electronica & firmware/celda braille con motor de celular/STL/assembly3 - soporte17-15.STL
Electronica & firmware/celda braille con motor de celular/STL/assembly3 - CAPUCHAMOTOR17-29.STL
Electronica & firmware/celda braille con motor de celular/STL/assembly3 - Pinderecho17-13.STL
Electronica & firmware/celda braille con motor de celular/STL/assembly3 - Pinizquierdo17-15.STL
Electronica & firmware/celda braille con motor de celular/STL/assembly3 - soporte17-14.STL
Electronica & firmware/celda braille con motor de celular/STL/assembly3 - motor-7.STL
Electronica & firmware/celda braille con motor de celular/STL/assembly3 - Pinderecho17-15.STL
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

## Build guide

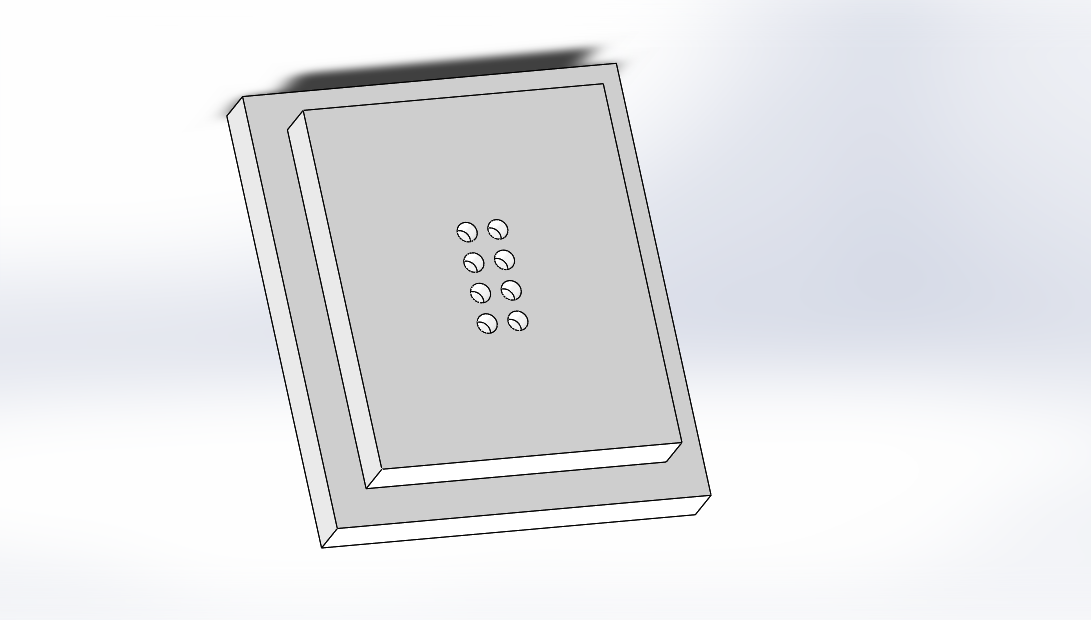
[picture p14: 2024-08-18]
Electronica & firmware/celda braille con motor de celular/image/assembly20.PNG

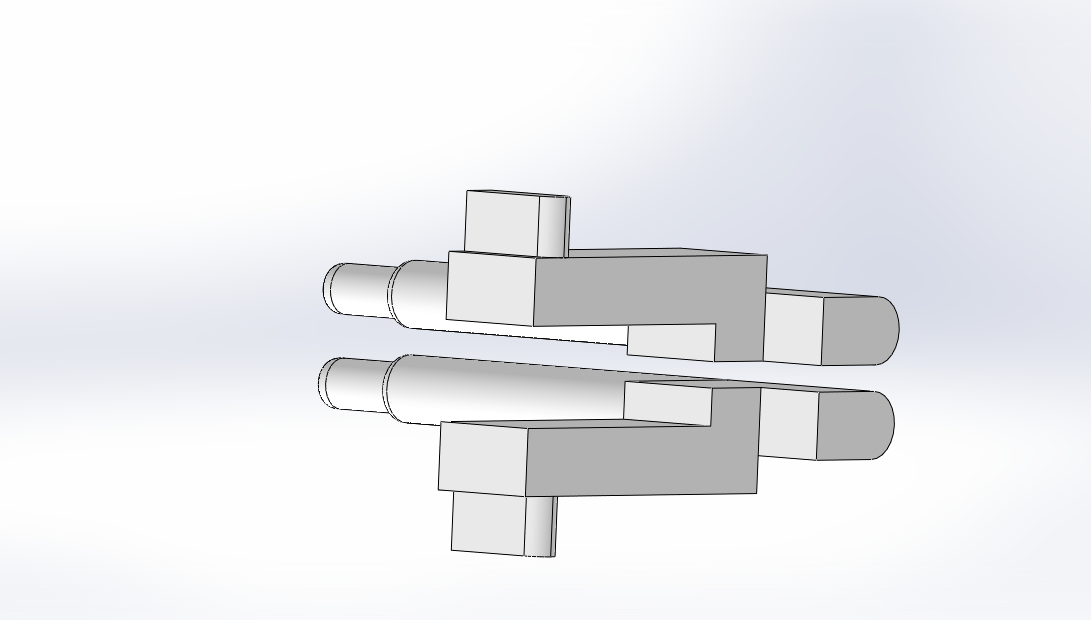
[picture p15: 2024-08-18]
Electronica & firmware/celda braille con motor de celular/image/assembly18.PNG

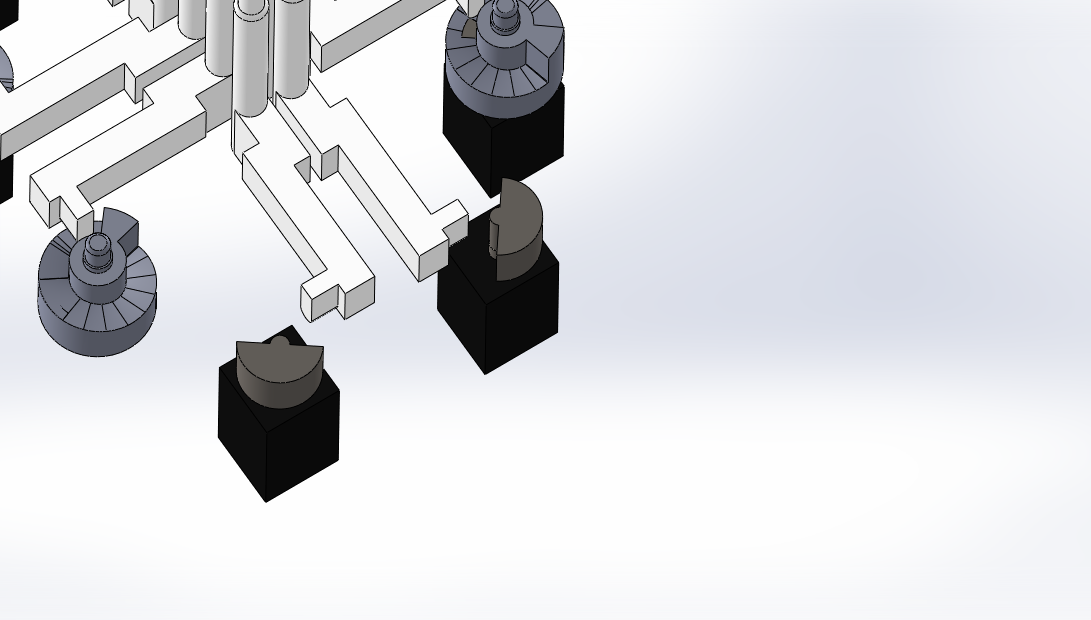
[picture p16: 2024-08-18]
Electronica & firmware/celda braille con motor de celular/image/assembly15.PNG

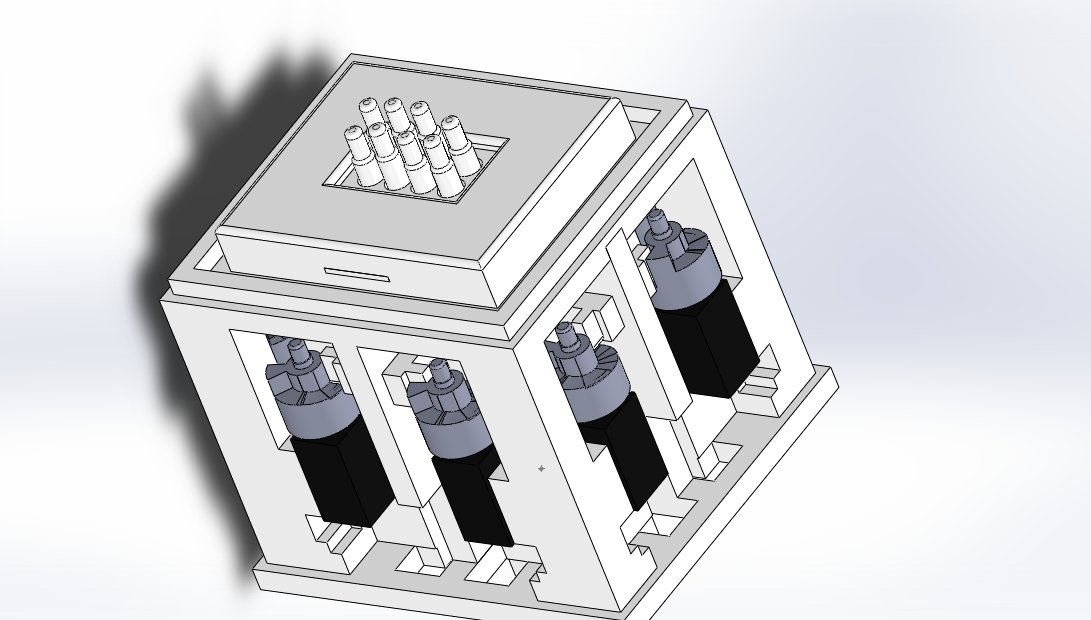
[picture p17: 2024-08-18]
Electronica & firmware/celda braille con motor de celular/image/assembly11.PNG

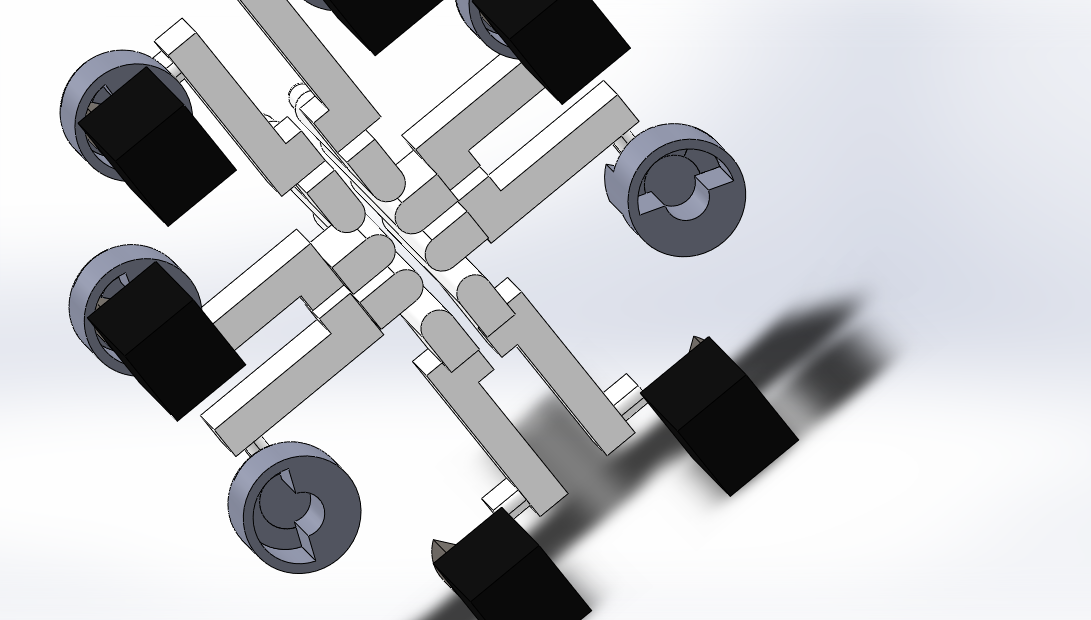
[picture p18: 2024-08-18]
Electronica & firmware/celda braille con motor de celular/image/assembly16.PNG

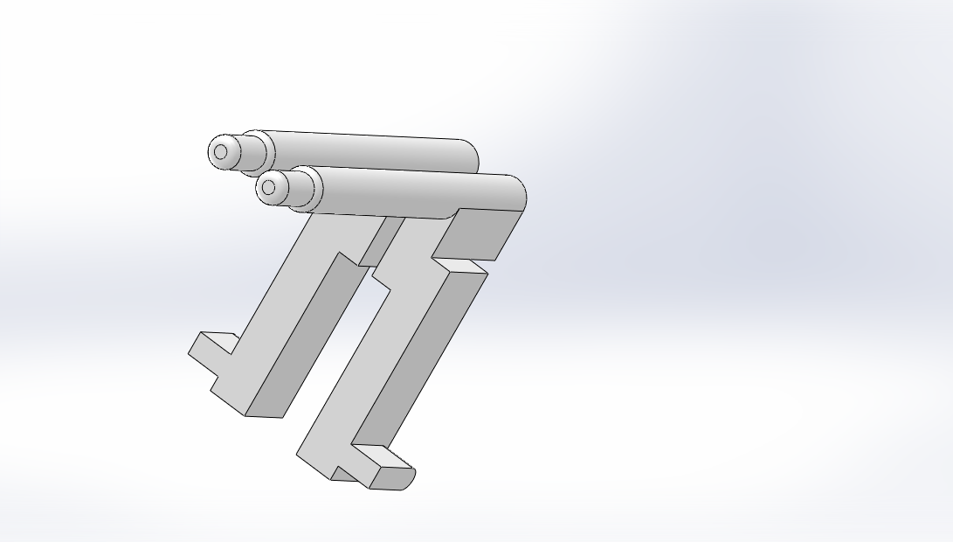
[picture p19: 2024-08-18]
Electronica & firmware/celda braille con motor de celular/image/assembly17.PNG

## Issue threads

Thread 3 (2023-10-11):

Next steps in development

chloe-everhart, 2023-10-11:
Hi,
Someone shared your project with me.
I had a conversation with someone who is interested in funding development.
How much would it cost to get this project to a place where a totally blind person could order one of these from an online store?
On a related note, that person is interested in funding development of an image that has a text based home screen/launcher, where the home screen a launcher that you can just scroll up and down in, through alist of favorites, followed by a list of all programs listed alphabetically.  It is hoped this will be of use to low vision people, totally blind people, light sensitive people (e-ink display friendly), and color blind people.
If you can give me a number, I'll take that back to the interested potential funder.

chloe-everhart, 2024-06-17:
el ingles sigue

Lo siento, que yo no escribo despues mucho tiempo.  Hablo un poco de Espanol.  Quiero aprender mas Espanol.  Que buena oportunidad por practicar!

Que ja esta lista en la pantalla braille?

Puedo ja pagar por se lo hace, si yo conozco un hombre con impresora 3D?

No se mucho sobre codifacacion o como hacer algo, o github.  Kuriatus de Quill OS dice a mi sobre este projekto.

Que necesitas por continuar el proyecto?

Espero, que tu escribes mas rapide que yo.

Gracias,
Chloe

English.  Spanish above.
English
I'm sorry, I haven't written for a long time. I speak a little spanish. I want to learn more Spanish. What a good opportunity to practice!

What is ready on the braille display?

Can I pay to have it done if I know a man with a 3D printer?

I don't know much about coding or how to do something, or github. Kuriatus from Quill OS tells me about this project.

What do you need to continue the project?

I hope you write faster than me.

Thank you,
Chloe

chloe-everhart, 2024-06-17:
Es mas facil para mi escribir que tener un reunion.  Puedemos escribir?
It's easier for me to write than to meet.  Could we write one another?

discapacidad5, 2024-06-27:
**Español:**

Hola Chloe,

En cuanto a tu pregunta sobre lo que necesitamos para continuar con el proyecto, necesitamos desarrollar el protocolo de comunicación HID de braille para que haya una comunicación efectiva entre el lector de pantalla y el dispositivo braille que estamos fabricando.

El diseño de la impresión en 3D corresponde a la parte física, es decir, la carcasa del dispositivo. Sin embargo, en este momento estamos enfocados en desarrollar la parte interna, el software que lo hará funcionar. Actualmente, estamos estancados en el desarrollo del protocolo de comunicación entre el dispositivo y los lectores de pantalla.

Lo que necesitamos para continuar el proyecto es alguien que conozca el protocolo HID de braille, algún programador que pueda desarrollar el controlador para que nuestros dispositivos sean reconocidos por los lectores de pantalla, ya sea en sistemas operativos Windows, Android o iPhone.

Una vez consigamos a la persona adecuada, podremos continuar con el desarrollo. Hasta ahora, se han presentado varios voluntarios, pero ninguno ha logrado desarrollar con éxito el controlador.

Seguimos esperando para poder avanzar, ya que necesitamos el controlador para poder realizar las pruebas. Si conoces a alguien que pueda ayudarnos a desarrollar este controlador, estaríamos encantados de recibir su apoyo. Necesitamos un controlador que permita que los lectores de pantalla reconozcan el dispositivo y le envíen la información que debe mostrar.

Gracias por tu interés y tu ayuda.

Saludos,
Cergio Monasterio
WhatsApp +584129994784

---

**English:**

Hi Chloe,

Regarding your question about what we need to continue with the project, we need to develop the HID braille communication protocol to ensure effective communication between the screen reader and the braille device we are creating.

The 3D printing design pertains to the physical part, that is, the device casing. However, we are currently focused on developing the internal part, the software that will make it work. Right now, we are stuck on developing the communication protocol between the device and the screen readers.

What we need to continue the project is someone who knows the HID braille protocol, a programmer who can develop the driver so that our devices are recognized by screen readers on Windows, Android, or iPhone operating systems.

Once we find the right person, we can continue with the development. So far, several volunteers have come forward, but none have successfully developed the driver.

We are still waiting to move forward because we need the driver to conduct tests. If you know someone who can help us develop this driver, we would be delighted to receive their support. We need a driver that allows screen readers to recognize the device and send the information it should display.

Thank you for your interest and your help.

Best regards,
Cergio Monasterio

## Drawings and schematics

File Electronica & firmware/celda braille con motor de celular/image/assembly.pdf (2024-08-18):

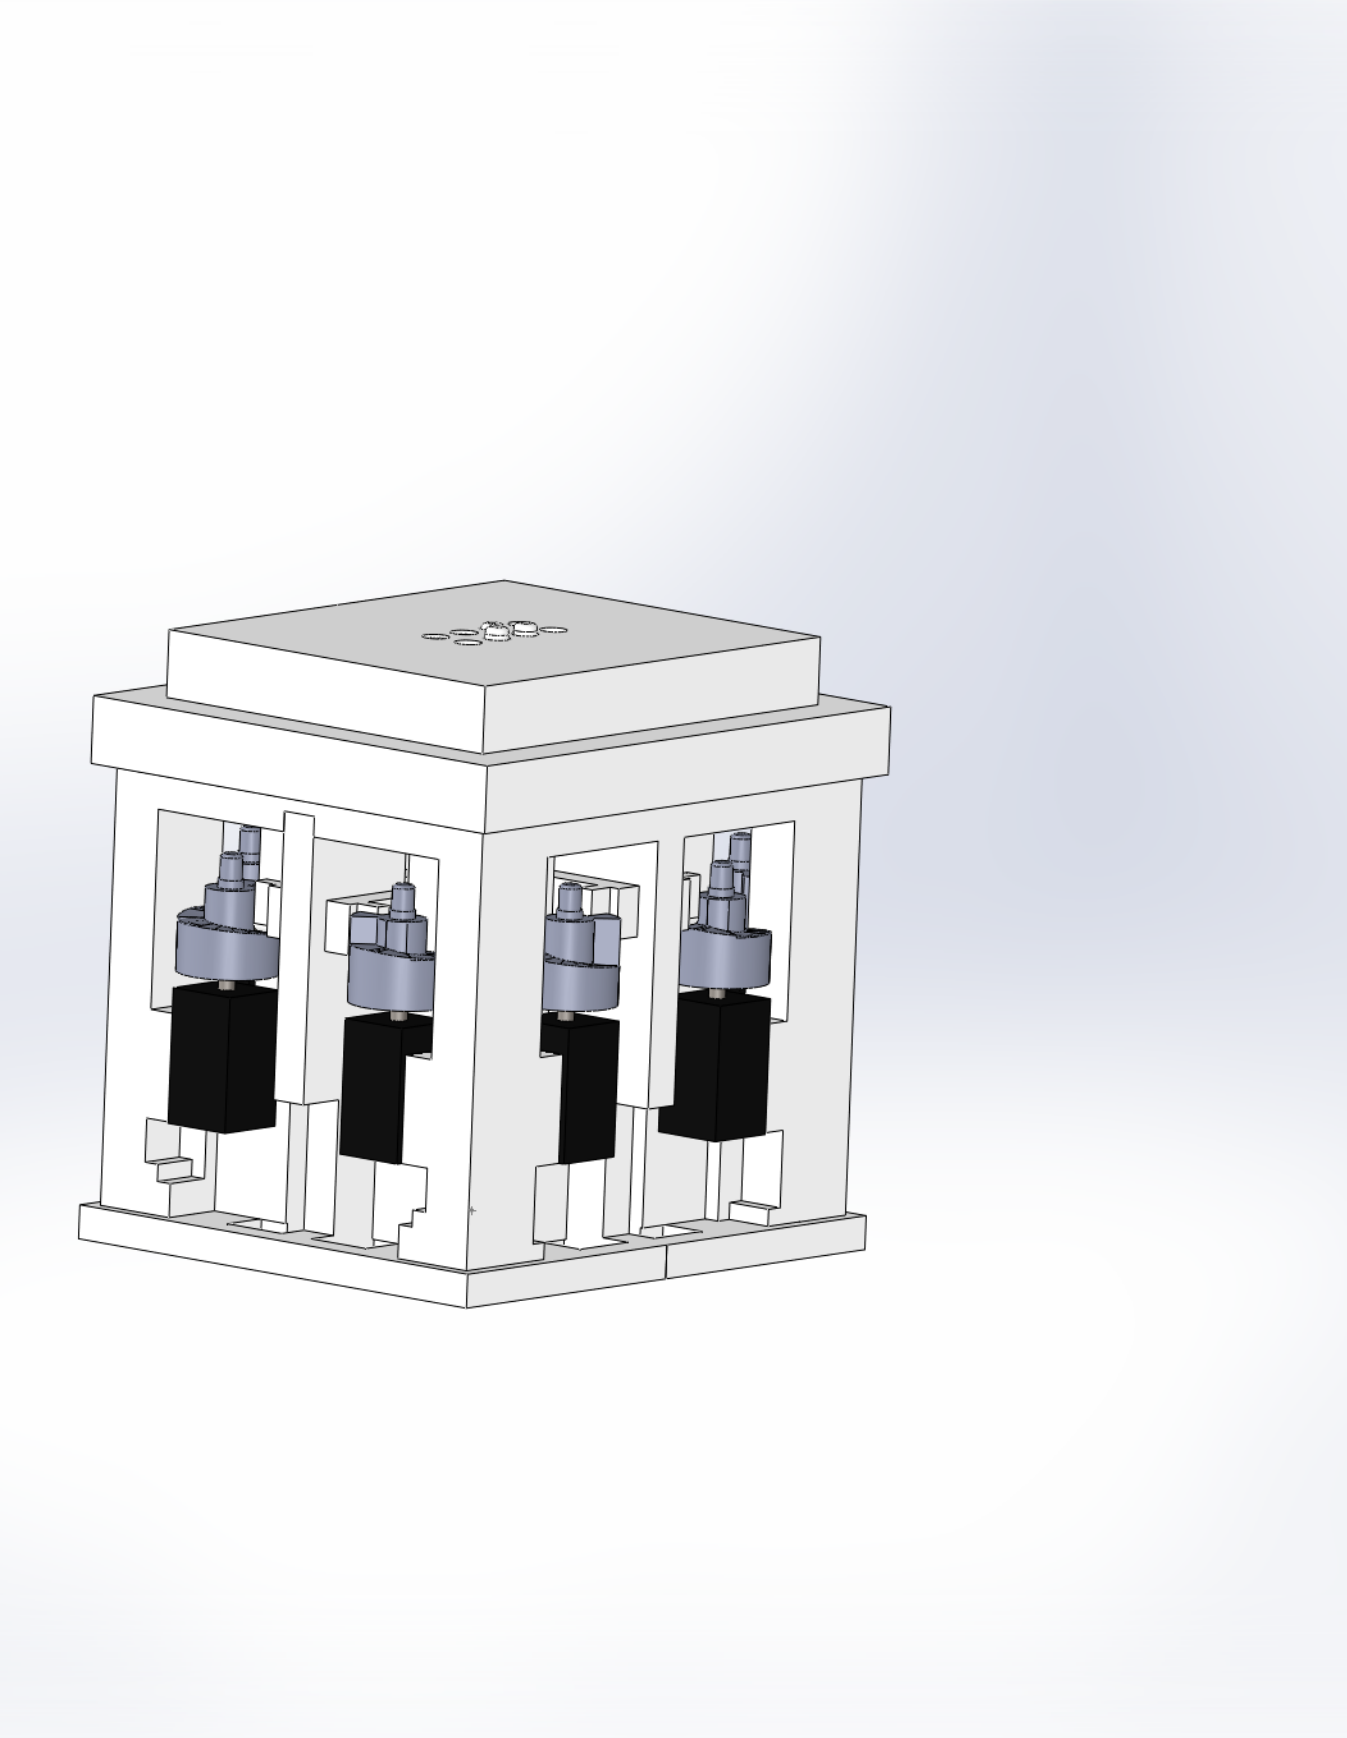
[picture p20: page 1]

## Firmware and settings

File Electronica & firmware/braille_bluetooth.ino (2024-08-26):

/*
 * Brailletouch - Open Source Braille Display
 *
 * Description:
 * This code is part of the Brailletouch project, an open-source initiative aimed at reducing the cost of braille displays.
 The project uses a combination of physical and virtual braille cells to make assistive technology more accessible.
 *
 * Project Repository:
 * GitHub: https://github.com/brailletouch/Brailletouch
 *
 * License:
 * This code is licensed under the Braille Touch Open and Community License (BTAC) v1.2.
 You are free to use, copy, modify, and distribute this code under the conditions of this license. For more details, 
 please review the LICENSE file in the repository.
 *
 * Contact:
 * Cergio Monasterio
 * WhatsApp: +58 412 999 4784 (Please communicate in Spanish only) 
 *
 * Date: 26/08/2024
 * Version: 1.1
 *
 * Copyright (c) 2024 Brailletouch
 * This code is provided "as is", without warranty of any kind. For licensing terms, see the LICENSE file.
 */


#include "BluetoothSerial.h"

#include <ESP32Servo.h>
#include <Stream.h> // Para poder tener una referencia a Serial

#if !defined(CONFIG_BT_ENABLED) || !defined(CONFIG_BLUEDROID_ENABLED)
#error Bluetooth is not enabled! Please run `make menuconfig` to and enable it
#endif
#define CELL 15
//int datos;
//int u = 0;
//int recibido[CELL];
BluetoothSerial SerialBT;
char data[16] ="brailletouch 01";

ESP32PWM pwm;
// posicioens de los servos
int right1 = 135;
int right2 = 180;
int center = 90;
int left1 = 45;
int left2 = 0;
int repetir = 5; // minimo 10
int ciclos = 1; // recomendado 1
int pausacaract = 1; // recomendado 1
int velocidad = 60; // recomendado 60 esto no debe controlar la velocidad si se lee con las celdas virtuales


Servo sevo1;
Servo sevo2;
Servo sevo3;
Servo sevo4;

int minUs = 500;
 int maxUs = 2400;
// These are all GPIO pins on the ESP32
// Recommended pins include 2,4,12-19,21-23,25-27,32-33 
int sevo1Pin = 19; // Un servo en el pin 15
int sevo2Pin = 17; // Otro servo en el pin 16
int sevo3Pin = 21; // Un servo en el pin 14
int sevo4Pin = 32; // Otro servo en el pin 32


class LeeUTF8 {

  public:

    LeeUTF8(Stream &entrada) :

      entrada(entrada),

      valorTemporal(0),

      valor(-1),

      bytesTotales(0),

      bytesLeidos(0) {};

    int16_t available() {

      if (this->valor == -1) {

        this->valor = this->read();

      }

      return (this->valor != -1);

    }

    int16_t read() {

      if (this->valor != -1) {

        int16_t valorLeido = this->valor;

        this->valor = -1;

        return valorLeido;

      }

      int16_t lectura = this->entrada.read();

      if (lectura < 0) {

        return -1;

      }

      if ((lectura & 0b11000000) == 0b10000000) {      // Los bytes que vienen después del primero

        if (this->bytesTotales > 1) { // Si se esperan en total más de un byte

          this->valorTemporal <<= 6; // Desplazamos el valor 6 bits a la izquierda 

          this->valorTemporal |= lectura & 0b00111111; // 10xxxxxx

          if (++this->bytesLeidos >= this->bytesTotales) { // Si ya se han leído todos los bytes esperados

            return this->resultado(this->valorTemporal); // Devolvemos el resultado

          }

          else {

            return -1; // No hay valor disponible aún

          }

        }

        else {

          return this->resultado(-2); // Error

        }

      }

      else if ((lectura & 0b11100000) == 0b11000000) { // El primero de dos bytes

        this->valorTemporal = lectura & 0b00011111;    // 110yyyyy

        return this->empezando(2);

      }

      else if ((lectura & 0b11110000) == 0b11100000) { // El primero de tres bytes

        this->valorTemporal = lectura & 0b00001111;    // 1110zzzz

        return this->empezando(3);

      }

      else if ((lectura & 0b11111000) == 0b11110000) { // El primero de cuatro bytes 

        this->valorTemporal = lectura & 0b00000111;    // 11110uuu

        return this->empezando(4);

      }

      else { // Asumimos que es un solo byte (aunque sea erróneo)

        return this->resultado(lectura);

      }

    }

  private:

    Stream &entrada;

    int16_t valorTemporal;

    int16_t valor;

    uint8_t bytesTotales;

    uint8_t bytesLeidos;

    int16_t empezando(uint8_t setBytesTotales) {

      this->bytesTotales = setBytesTotales;

      this->bytesLeidos = 1;

      return -1;

    }

    int16_t resultado(int16_t valorObtenido) {

      this->bytesTotales = 0;

      this->bytesLeidos = 0;

      this->valor = -1;

      return valorObtenido;

    }

};





// Clase para controlar un buffer de únicamente "valores númericos de caracteres Braille"

class BufferBraille {

  public:

    // Constructor al que se le indica cuántos caracteres Braille va a tener

    BufferBraille(size_t longitud) :

      longitud(longitud), 

      buffer(new int16_t[longitud]),

      indiceEntrada(0),

      limpiarAntes(false) { this->clear(); };



    // Destructor, no hace falta invocarlo

    ~BufferBraille() { delete[] this->buffer; }



    // Para limpiar el buffer y pone el índice de entrada a 0

    void clear() {

      for (size_t i = 0; i < this->longitud; i++) {

        this->buffer[i] = 0x2800;

      }

      this->indiceEntrada = 0;

      this->limpiarAntes = false;

    }



    // Obtiene el valor de la posición indicada. Si se sale de rango devuelve cero

    int16_t get(size_t indice) const {

      if (indice >= this->longitud) {

        return 0x2800;

      }

      return this->buffer[indice];

    }



    // Establece el valor en la posición dada. Si no se indica la posición (indice) entonces lo mete a continuación del último metido

    // Retorna true si lo ha metido y false si no lo ha mentido porque se sale del rango

    bool set(int16_t valor, size_t indice = static_cast<size_t>(-1)) {

      if (this->limpiarAntes) {

        this->clear();

      }

      if (indice == static_cast<size_t>(-1)) {

        indice = this->indiceEntrada;

      }

      this->indiceEntrada = indice + 1;

      if (indice >= this->longitud) {

        return false;

      }

      if ((valor < 0x2800) || (valor > 0x28FF)) {

        valor = 0x2800;

      }

      this->buffer[indice] = valor;

      return true;

    }



    // Si se invoca esta función, el buffer permanecerá igual, pero se borrará en cuanto se le añada otro valor

    void setLimpiarAntes() {

      this->limpiarAntes = true;

    }



    // Retorna el tamaño del buffer (el valor que se le pasó en el constructor)

    size_t size() const {

      return this->longitud;

    }

  private:

    size_t longitud;

    int16_t* const buffer;

    size_t indiceEntrada;

    bool limpiarAntes;

};





LeeUTF8 leeUTF8(Serial);
LeeUTF8 LeeBTUTF8(SerialBT);


BufferBraille buffer(CELL); // Declaramos el buffer de 20 caracteres para las pruebas



void setup() {

  ESP32PWM::allocateTimer(0);
  ESP32PWM::allocateTimer(1);
  ESP32PWM::allocateTimer(2);
  ESP32PWM::allocateTimer(3);
  Serial.begin(115200);
  SerialBT.begin("ESP32test"); //Bluetooth device name
  Serial.println("The device started, now you can pair it with bluetooth!");
  sevo1.setPeriodHertz(50);      // Standard 50hz servo
  sevo2.setPeriodHertz(50);      // Standard 50hz servo
  sevo3.setPeriodHertz(50);      // Standard 50hz servo
  sevo4.setPeriodHertz(50);      // Standard 50hz servo

  Serial.println(F("Meta cararteres Braille en UTF-8"));

}



void loop() {

  if (leeUTF8.available() || LeeBTUTF8.available()) {

    int dato; // Leemos el dato ya disponible. Cuidado, la variable ha de ser int;

             if (leeUTF8.available()) { // Si hay dato en el Serial
             dato = leeUTF8.read(); // Lo lee del Serial
              }
         else {
             dato = LeeBTUTF8.read(); // Lo lee del BluetoothSerial si no lo había en el Serial
              } 

    if ((dato >= 0x2800) && (dato <= 0x28FF)) { // Si el dato corresponde a un carácter Braille

      if (buffer.set(dato)) {                   // Metemos el carácter en el buffer y si no se ha desbordado...

//        for (size_t i = 0; i < buffer.size(); i++) {  // .. recorremos todo el buffer (no hace falta recordar qué tamaño tiene ya que lo podemos saber con buffer.size()

//          Serial.print(' ');                    // Ponemos un caráctes de separador

          Serial.print(dato, HEX);     // Mostramos el valor en hexadecimal
          Serial.print(' ');                    // Ponemos un caráctes de separador
//          Serial.println(i);
//          Serial.println("recibiendo datos braile");                   // recibe datos braille
//          Serial.println();                   // Deja una línea en blanco
          servo_disp(dato);
          delay(velocidad);

//        }

        Serial.println();                       // Terminamos la línea

      }

    }

    else if (dato == 13) {                        // Si el dato que ha entrado es un retorno de carro...

      buffer.setLimpiarAntes();                   // Le indicamos al buffer que queremos que se mantenga, pero que se borre antes de meter el próximo dato

      for (size_t i = 0; i < buffer.size(); i++) {// Mostramos el contenido del buffer para verificas que mantiene lo que tenía

//        Serial.println("datos del boffer antes de borrar");
        Serial.print(' ');

        Serial.print(buffer.get(i), HEX);

      }

      Serial.println();

    }

     else if ((dato >= 0x0020) && (dato <= 0x27FF) || (dato >= 0x2900)) {   // lo datos no son braille
     
      Serial.println("datos no braile");                   // recibe datos no braille
      Serial.println(dato, HEX);
      Serial.println(dato);
      Serial.write(dato);        
      Serial.println();                   // Deja una línea en blanco
      delay(1);         //   controla la velocidad  con que sale el carater

      // codigo para probar celda virtual desde la app de android

                if (dato == '1') {
                   Serial.println("Valor 0");
                   servo_disp(buffer.get(0));
                   Serial.println(buffer.get(0));
                  }
                else  if (dato == '2') {
                   Serial.println("Valor 1");
                   servo_disp(buffer.get(1));
                   Serial.println(buffer.get(1));
                  }
                else  if (dato == '3') {
                   Serial.println("Valor 2");
                   servo_disp(buffer.get(2));
                   Serial.println(buffer.get(2));
                  }
                else  if (dato == '4') {
                   Serial.println("Valor 3");
                   servo_disp(buffer.get(3));
                   Serial.println(buffer.get(3));
                  }
                else  if (dato == '5') {
                   Serial.println("Valor 4");
                   servo_disp(buffer.get(4));
                   Serial.println(buffer.get(4));
                  }
                else  if (dato == '6') {
                   Serial.println("Valor 5");
                   servo_disp(buffer.get(5));
                   Serial.println(buffer.get(5));
                  }
                else  if (dato == '7') {
                   Serial.println("Valor 6");
                   servo_disp(buffer.get(6));
                   Serial.println(buffer.get(6));
                  }
                else  if (dato == '8') {
                   Serial.println("Valor 7");
                   servo_disp(buffer.get(7));
                   Serial.println(buffer.get(7));
                  }
                else  if (dato == '9') {
                   Serial.println("Valor 8");
                   servo_disp(buffer.get(8));
                   Serial.println(buffer.get(8));
                  }
                else  if (dato == '0') {
                   Serial.println("Valor 9");
                   servo_disp(buffer.get(9));
                   Serial.println(buffer.get(9));
                  }
                else  if (dato == 'a') {
                   Serial.println("Valor 10");
                   servo_disp(buffer.get(10));
                   Serial.println(buffer.get(10));
                  }
                else  if (dato == 'b') {
                   Serial.println("Valor 11");
                   servo_disp(buffer.get(11));
                   Serial.println(buffer.get(11));
                  }
                else  if (dato == 'c') {
                   Serial.println("Valor 12");
                   servo_disp(buffer.get(12));
                   Serial.println(buffer.get(12));
                  }
                else  if (dato == 'd') {
                   Serial.println("Valor 13");
                   servo_disp(buffer.get(13));
                   Serial.println(buffer.get(13));
                  }
                else  if (dato == 'e') {
                   Serial.println("Valor 14");
                   servo_disp(buffer.get(14));
                   Serial.println(buffer.get(14));
                  }
                else  if (dato == 'f') {
                   Serial.println("Valor 15");
                   servo_disp(buffer.get(15));
                   Serial.println(buffer.get(15));
                  }
                else  if (dato == 'g') {
                   Serial.println("Valor 16");
                   servo_disp(buffer.get(16));
                   Serial.println(buffer.get(16));
                  }
                else  if (dato == 'h') {
                   Serial.println("Valor 17");
                   servo_disp(buffer.get(17));
                   Serial.println(buffer.get(17));
                  }
                else  if (dato == 'i') {
                   Serial.println("Valor 18");
                   servo_disp(buffer.get(18));
                   Serial.println(buffer.get(18));
                  }
                else  if (dato == 'j') {
                   Serial.println("Valor 19");
                   servo_disp(buffer.get(19));
                   Serial.println(buffer.get(19));
                 }
                else  if (dato == 'k') { // pone todo en blanco
                    Serial.println("lebanto el dedo");
                    SerialBT.println("lebanto el dedo");
                    sevo1.attach(sevo1Pin, minUs, maxUs);
                    sevo2.attach(sevo2Pin, minUs, maxUs);
                    pwm.attachPin(27, 10000);//10khz
                    sevo3.attach(sevo3Pin, minUs, maxUs);
                    sevo4.attach(sevo4Pin, minUs, maxUs);
                    delay(pausacaract);
                    sevo1.write(center);
                    delay(pausacaract);
                    sevo2.write(center);
                    delay(pausacaract);
                    sevo3.write(center);
                    delay(pausacaract);
                    sevo4.write(center);
                    delay(pausacaract);
                
                  }
                  
                                             
             else {
                Serial.println("otro dato");
                Serial.println();                   // Deja una línea en blanco
                  }    

            }
   
      }


}





void servo_disp(int dato)
{
//delay(velocidad);         //   controla la velocidad  con que sale el carater
  if ((dato >= 0x2800) && (dato <= 0x28FF)) {
        sevo1.attach(sevo1Pin, minUs, maxUs);
        sevo2.attach(sevo2Pin, minUs, maxUs);
        pwm.attachPin(27, 10000);//10khz
        sevo3.attach(sevo3Pin, minUs, maxUs);
        sevo4.attach(sevo4Pin, minUs, maxUs);
        delay(pausacaract);

  
  
  
  
for (int i = 0; i < repetir; i++)
        {      
    if(( bitRead(dato, 0) == 0) && ( bitRead(dato, 1) == 0 ) && ( bitRead(dato, 2) == 0) && ( bitRead(dato, 3) == 0 ) && ( bitRead(dato, 4) == 0) && ( bitRead(dato, 5) == 0 ) && ( bitRead(dato, 6) == 0) && ( bitRead(dato, 7) == 0 ))
     {
      for (int index = 0; index < ciclos; index++)
        {
        sevo1.write(center);
        delay(pausacaract);
        sevo2.write(center);
        delay(pausacaract);
        sevo3.write(center);
        delay(pausacaract);
        sevo4.write(center);
        delay(pausacaract);
                if( i == repetir -1 )
          {
           Serial.print("Espacio en blanco...\n"); 
           SerialBT.print("Espacio en blanco...\n");  
          }
        } 
  
      }      
    if(( bitRead(dato, 0) == 1) && ( bitRead(dato, 3) == 1 ) )
     {
       for (int index = 0; index < ciclos; index++)
      {
        sevo1.write(left2);   
        delay(pausacaract);
   if(( bitRead(dato, 0) == 0) && ( bitRead(dato, 3) == 0 ))
      {
       if (sevo1.read() != center)   // si la posicion del servo es diferete a la ultima 
         { 
        sevo1.write(center);
        delay(pausacaract);
         }

      }
   if(( bitRead(dato, 1) == 0) && ( bitRead(dato, 4) == 0 ))
      {
       if (sevo2.read() != center)   //  si la posicion del servo es diferete a la ultima 
         { 
        sevo2.write(center);
        delay(pausacaract);
         }
      }
   if(( bitRead(dato, 2) == 0) && ( bitRead(dato, 5) == 0 ))
      {
       if (sevo3.read() != center)   //  si la posicion del servo es diferete a la ultima 
         { 
        sevo3.write(center);
        delay(pausacaract);
         }
      }      
   if(( bitRead(dato, 6) == 0) && ( bitRead(dato, 7) == 0 ))
      {
       if (sevo4.read() != center)   // si la posicion del servo es diferete a la ultima 
         { 
        sevo4.write(center);
        delay(pausacaract);
         }

      }

      }
     if( i == repetir -1 )
       {      
       Serial.print("punto 1 y 4...\n"); 
       SerialBT.print("punto 1 y 4...\n"); 
      }
    }     
     if(( bitRead(dato, 0) == 1) && ( bitRead(dato, 3) == 0 ) )
      {  
     for (int index = 0; index < ciclos; index++)
       {
        sevo1.write(left1);
        delay(pausacaract);

   if(( bitRead(dato, 0) == 0) && ( bitRead(dato, 3) == 0 ))
      {
       if (sevo1.read() != center)   // si la posicion del servo es diferete a la ultima 
         { 
        sevo1.write(center);
        delay(pausacaract);
         }

      }
   if(( bitRead(dato, 1) == 0) && ( bitRead(dato, 4) == 0 ))
      {
       if (sevo2.read() != center)   //  si la posicion del servo es diferete a la ultima 
         { 
        sevo2.write(center);
        delay(pausacaract);
         }
      }
   if(( bitRead(dato, 2) == 0) && ( bitRead(dato, 5) == 0 ))
      {
       if (sevo3.read() != center)   //  si la posicion del servo es diferete a la ultima 
         { 
        sevo3.write(center);
        delay(pausacaract);
         }
      }      
   if(( bitRead(dato, 6) == 0) && ( bitRead(dato, 7) == 0 ))
      {
       if (sevo4.read() != center)   // si la posicion del servo es diferete a la ultima 
         { 
        sevo4.write(center);
        delay(pausacaract);
         }
       }
      }
       if( i == repetir -1 )
        {
       Serial.print("punto 1...\n");
       SerialBT.print("punto 1...\n");
        }
     }     
    if(( bitRead(dato, 3) == 1) && ( bitRead(dato, 0) == 0 ))
      {
     for (int index = 0; index < ciclos; index++)
      {      
        sevo1.write(right1);
        delay(pausacaract);
   if(( bitRead(dato, 0) == 0) && ( bitRead(dato, 3) == 0 ))
      {
       if (sevo1.read() != center)   // si la posicion del servo es diferete a la ultima 
         { 
        sevo1.write(center);
        delay(pausacaract);
         }

      }
   if(( bitRead(dato, 1) == 0) && ( bitRead(dato, 4) == 0 ))
      {
       if (sevo2.read() != center)   //  si la posicion del servo es diferete a la ultima 
         { 
        sevo2.write(center);
        delay(pausacaract);
         }
      }
   if(( bitRead(dato, 2) == 0) && ( bitRead(dato, 5) == 0 ))
      {
       if (sevo3.read() != center)   //  si la posicion del servo es diferete a la ultima 
         { 
        sevo3.write(center);
        delay(pausacaract);
         }
      }      
   if(( bitRead(dato, 6) == 0) && ( bitRead(dato, 7) == 0 ))
      {
       if (sevo4.read() != center)   // si la posicion del servo es diferete a la ultima 
         { 
        sevo4.write(center);
        delay(pausacaract);
         }
      }
     }
      if( i == repetir -1 )
       {
      Serial.print("punto 4...\n");
      SerialBT.print("punto 4...\n");
      }
     }       
    if(( bitRead(dato, 1) == 1) && ( bitRead(dato, 4) == 1 ) )
     {    
    for (int index = 0; index < ciclos; index++)
       {      
        sevo2.write(left2);
        delay(pausacaract);
   if(( bitRead(dato, 0) == 0) && ( bitRead(dato, 3) == 0 ))
      {
       if (sevo1.read() != center)   // si la posicion del servo es diferete a la ultima 
         { 
        sevo1.write(center);
        delay(pausacaract);
         }

      }
   if(( bitRead(dato, 1) == 0) && ( bitRead(dato, 4) == 0 ))
      {
       if (sevo2.read() != center)   //  si la posicion del servo es diferete a la ultima 
         { 
        sevo2.write(center);
        delay(pausacaract);
         }
      }
   if(( bitRead(dato, 2) == 0) && ( bitRead(dato, 5) == 0 ))
      {
       if (sevo3.read() != center)   //  si la posicion del servo es diferete a la ultima 
         { 
        sevo3.write(center);
        delay(pausacaract);
         }
      }      
   if(( bitRead(dato, 6) == 0) && ( bitRead(dato, 7) == 0 ))
      {
       if (sevo4.read() != center)   // si la posicion del servo es diferete a la ultima 
         { 
        sevo4.write(center);
        delay(pausacaract);
         }
      }
     }
      if( i == repetir -1 )
      {
      Serial.print("punto 2 y 5...\n");
      SerialBT.print("punto 2 y 5...\n");
     }
     }
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

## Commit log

2021-12-04 ajustes en del void servo_disp / settings on the void servo_disp
    se realizaron ajustes en la celda braille para mejor funcionamiento se realizo el ajuste en del void servo_disp para que funcione como se debe /
    Adjustments were made in the braille cell for better operation, the adjustment was made in the void servo_disp so that it works as it should
2021-12-04 modelos 3d / 3d models
    Esta carpeta contiene los modelos de piezas en 3D para editar e imprimir
2021-12-04 archivos originales / original files
    archivos originales hechos en SketchUp https://app.sketchup.com/app /
    original files made in SketchUp https://app.sketchup.com/app
    [barilla.skp, caja modelo.skp, celda braille.skp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]
2021-12-04 archivos stl / stl files
    [barilla.stl, celda braille.stl, celda completa.stl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]
2021-12-04 otros formato / other formats
    otros formatos para editar y mejorar /
    other formats to edit and improve
    [celda completa.FCStd, celda completa.dwg, celda completa.dxf]
2021-12-14 se agrego else if
    se agrego else if en la función servo_disp
2024-08-17 Create README.md
    Added 3D files, electrical schematic, and firmware for Braille cell with vibrating motors. Includes documentation in both English and Spanish on operation and assembly.
    Agregados archivos 3D, esquema eléctrico y firmware para celda Braille con motores vibratorios. Incluye documentación en español e inglés sobre el funcionamiento y ensamblaje.
2024-08-17 Create stl
2025-05-15 Update LICENCIA.md
    Notas sobre los cambios:
    Eliminación de la Sección 18 Original: La Sección 18 original ("License Versions") fue eliminada por ser la fuente de la ambigüedad y permitir una interpretación incorrecta.
    Nueva Sección 10: Versiones Futuras y Inmutabilidad: Se creó una nueva Sección 10 con un título explícito ("Versiones Futuras: Inmutabilidad hacia Restricciones"). Esta sección ahora articula clarame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
    Que el licenciante original puede publicar nuevas versiones, pero SÓLO para clarificar, añadir cobertura a nuevos aspectos técnicos o hacer la licencia MÁS permisiva.
    Que NUNCA una nueva versión puede imponer restricciones adicionales o reducir derechos.
    C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
